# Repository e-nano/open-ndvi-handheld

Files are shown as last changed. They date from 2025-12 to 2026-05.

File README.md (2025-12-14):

# Open NDVI Handheld

**A reference open-source handheld NDVI instrument**

Open-source handheld NDVI device based on the ESP32 Feather V2 and AS7265x Triad spectral sensors, intended as a transparent reference design for vegetation sensing, experimentation, and system integration.

## What is this project?

This repository contains a fully open hardware and software implementation of a handheld NDVI (Normalized Difference Vegetation Index) measurement device.

It is designed to:

- Expose how NDVI measurements are actually produced
- Enable validation, comparison, and experimentation
- Serve as a building block for larger sensing systems

The device measures reflected light in visible and near-infrared bands and computes NDVI locally, producing structured digital output suitable for further analysis or integration.

## Why E-Nano is releasing this

E-Nano develops sensing systems and automation platforms that turn physical measurements into structured, actionable data across multiple industries (sports surfaces, agriculture, construction, and environmental monitoring).

In practice, we repeatedly encountered the same problem:

**Many vegetation indices are treated as "black boxes", making validation, comparison, and integration difficult.**

This project exists to address that problem by providing:

- A transparent reference implementation
- A known, inspectable signal path
- A device that can be understood, modified, and extended

This open handheld NDVI tool is not a commercial product, but a reference instrument that complements E-Nano's wider ecosystem.

## What NDVI means (briefly)

NDVI compares how vegetation reflects:

- **Red light** (absorbed for photosynthesis)
- **Near-infrared light** (strongly reflected by healthy plant structure)

The resulting value typically ranges from:

- **High NDVI (≈ 0.5–0.9)** → healthy, dense vegetation
- **Moderate NDVI (≈ 0.2–0.5)** → stressed or sparse vegetation
- **Low / negative NDVI** → soil, hard surfaces, water

NDVI is an indicator, not a diagnosis, and its reliability depends heavily on measurement context and methodology.

## What this device is intended for

This project is intended for:

- Engineers building or validating sensing systems
- Researchers and students studying vegetation indices
- Turf, agronomy, or environmental professionals exploring NDVI behaviour
- Developers integrating NDVI into larger data pipelines
- Anyone who wants to understand NDVI beyond a single numeric output

It is not intended to replace certified instruments or professional judgement.

## What you will find in this repository

This repository contains everything required to understand and reproduce the device:

### Firmware
- Arduino-based ESP32 code
- NDVI calculation logic
- Sensor configuration and data output

### Hardware
- Full schematic and PCB design (Fusion / Eagle)
- Manufacturing files (Gerbers, BOM)
- Modular carrier-board architecture

### Mechanical
- 3D-printable enclosure (STL + STEP)
- Assembly notes

### Documentation
- Assembly and wiring guides
- NDVI theory and limitations
- Example output data

Nothing is hidden behind proprietary firmware or closed hardware.

## Quick Start Guide

### 📦 **Components Required (~$244 total)**

| Component | Cost | Supplier |
|---|---|---|
| [ESP32 Feather V2](https://www.adafruit.com/product/5400) | $22.50 | Adafruit |
| [2x AS7265x Sensors](https://www.sparkfun.com/products/15050) | $74.95 each | SparkFun |
| [240x240 LCD Display](https://shop.pimoroni.com/products/1-3-spi-colour-lcd-240x240-breakout) | $16.50 | Pimoroni |
| [LiPo Battery](https://shop.pimoroni.com/products/lipo-battery-pack) | $12.00 | Pimoroni |
| Custom Carrier PCB | ~$20 | PCB Manufacturer |
| 3D Printed Enclosure | ~$15 | 3D Printing Service |
| Switches & Connectors | ~$8 | Generic |

### 🔧 **Build Process**

1. **Order components** and send `hardware/gerbers/` files to PCB manufacturer
2. **Assemble** carrier PCB with all modules (see [Assembly Guide](docs/assembly_guide.md))
3. **Program firmware** using Arduino IDE (see setup below)
4. **Test device** and take first measurements

### 💻 **Arduino IDE Setup**

1. **Install Arduino IDE** from [arduino.cc](https://www.arduino.cc/)

2. **Add ESP32 Board Support:**
   - File → Preferences
   - Additional Board Manager URLs: `https://espressif.github.io/arduino-esp32/package_esp32_dev_index.json`
   - Tools → Board → Boards Manager → Search "esp32" → Install

3. **Install Libraries** (Library Manager):
   - SparkFun AS7265x Arduino Library
   - Adafruit ST7735 and ST7789 Library
   - Adafruit GFX Library

4. **Programming:**
   - Connect ESP32 via USB
   - Board: "Adafruit ESP32 Feather"
   - Open: `firmware/ndvi_handheld/ndvi_handheld.ino`
   - Upload ⬆️

### 📱 **Using the Device**

**Display shows:**
- **Large NDVI number** (color-coded: green=healthy, yellow=moderate, white=sparse)
- **Battery percentage**
- **"LOW LIGHT"** warning when too dark for accurate readings

## Design philosophy

Key principles behind this project:

**Transparency over optimisation**
Readability and traceability are prioritised over maximum performance.

**Reference, not product**
This is a baseline instrument meant to be built upon.

**Interoperability**
Data output is designed to be easy to log, parse, and integrate.

**Modularity**
Firmware, hardware, and enclosure can all be adapted independently.

## Relationship to E-Nano's commercial systems

This open project:

- Does not include E-Nano's proprietary analysis pipelines
- Does not include commercial calibration workflows
- Does not claim agronomic decision-making accuracy

E-Nano's commercial offerings build on similar sensing principles, but add:

- Controlled calibration
- Repeatability guarantees
- Quality assurance
- Integration into larger automation and analysis platforms

This repository exists to enable understanding and experimentation, not to replace professional systems.

## Repository structure (high level)

```
open-ndvi-handheld/
├── firmware/        # ESP32 firmware (Arduino)
├── hardware/        # Schematic, PCB, BOM, Gerbers
├── mechanical/      # 3D-printable enclosure
├── docs/            # Assembly, theory, documentation
└── LICENSES/        # Multi-license structure
```

## Licensing

Different parts of the project use appropriate open licences:

- **Firmware**: MIT
- **Hardware (schematic & PCB)**: CERN OHL-W v2
- **Mechanical design**: CC BY-SA 4.0
- **Documentation**: CC BY 4.0

See the `LICENSES/` directory for full texts.

## Documentation

- 🔧 [Assembly Guide](docs/assembly_guide.md) - Detailed assembly instructions
- 📐 [Wiring & Pinout](docs/wiring_and_pinout.md) - Technical connections
- 🧪 [NDVI Theory](docs/ndvi_theory.md) - Scientific background
- ❓ [FAQ](docs/faq.md) - Common questions and troubleshooting

## Contributing

Contributions are welcome, particularly:

- Documentation improvements
- Validation experiments
- Firmware extensions
- Mechanical or hardware variants

Please read:

- [CONTRIBUTING.md](CONTRIBUTING.md)
- [CODE_OF_CONDUCT.md](CODE_OF_CONDUCT.md)

## Disclaimer

This is an experimental reference instrument provided as-is.

It is not certified, not safety-critical, and not intended to be used as the sole basis for agronomic or environmental decisions.

Released by E-Nano to support transparency, learning, and open experimentation in vegetation sensing.

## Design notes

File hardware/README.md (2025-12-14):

# Hardware - Open NDVI Handheld

This directory contains all hardware design files for the Open NDVI Handheld device.

## Overview

The hardware consists of a custom carrier PCB designed to connect modular components: ESP32 Feather V2, dual AS7265x spectral sensors, ST7789 240x240 LCD display, battery, switches, and connectors. This modular approach simplifies assembly, troubleshooting, and component replacement.

## Directory Structure

- `fusion_eagle/` - Autodesk Fusion/Eagle design files
- `gerbers/` - Manufacturing files for PCB production
- `bom/` - Bill of Materials
- `outputs/` - Generated documentation (schematics, assembly drawings)
- `datasheets/` - Component datasheets (AS7265x, ESP32, SSD1351, etc.)

## Design Files

### Fusion/Eagle Files
- `ndvi_v1.sch` - Schematic design
- `ndvi_v1.brd` - PCB layout
- `ndvi_v1.f3d` - Fusion 360 3D model
- `ndvi_v1.f2d` - Fusion 360 2D drawings

### Manufacturing Outputs
- `gerbers/ndvi_gerbers.zip` - Gerber files for PCB fabrication
- `bom/bom.csv` - Complete bill of materials
- `outputs/schematic.pdf` - Printable schematic
- `outputs/pcb_top.pdf` - Top layer assembly drawing
- `outputs/pcb_bottom.pdf` - Bottom layer assembly drawing

## Key Components

- **ESP32 Feather V2** (Adafruit #5400) - Main microcontroller with WiFi/Bluetooth
- **2x AS7265x Triad Sensors** (SparkFun SEN-15050) - 18-channel spectral sensors
- **ST7789 240x240 LCD** (Pimoroni 1.3" SPI) - Color display with simplified interface
- **LiPo Battery** (Pimoroni) - Rechargeable power source
- **Power Switch** - On/off control
- **Momentary Button** - Measurement trigger (A0)
- **Carrier PCB** - Custom board connecting all modules
- **Headers/Connectors** - Modular connections for easy assembly

## PCB Specifications

- 4-layer PCB design
- Dimensions: TBD
- Thickness: 1.6mm standard
- Finish: HASL or ENIG
- Via size: 0.2mm minimum

## Assembly Notes

See `mechanical/assembly_notes.md` for complete assembly instructions.

## License

Hardware designs are licensed under CERN OHL-W v2. See `LICENSES/LICENSE_HARDWARE_CERN-OHL-W.txt`.

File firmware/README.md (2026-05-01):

# Firmware - Open NDVI Handheld

- This folder now contains the ESP32 firmware structure copied from `Manti-S_CalibrationCode`.

## Layout

- `platformio.ini`
  - PlatformIO project config for `adafruit_feather_esp32_v2`
- `src/main.cpp`
  - Main ESP32 application
- `src/as7265x_calibration_data.h`
  - Embedded calibration tables
- `lib/SparkFun_Spectral_Triad_AS7265X/`
  - Local patched AS7265X library used by the firmware
- `ndvi_handheld/ndvi_handheld.ino`
  - Older Arduino sketch retained for reference

## Notes

- The active PlatformIO firmware is the `src/` project, not the older `.ino` sketch.
- The copied firmware includes:
  - Dual AS7265X sensor handling
  - ST7789 display output
  - Battery monitoring
  - BLE status service
  - Calibration storage via `Preferences`

## Build

```bash
cd /home/robert/Documents/Manti-S/open-ndvi-handheld/firmware
pio run
```

## Upload

```bash
cd /home/robert/Documents/Manti-S/open-ndvi-handheld/firmware
pio run --target upload
```

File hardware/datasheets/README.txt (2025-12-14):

# Component Datasheets

This directory contains datasheets for the hardware components used in the Open NDVI Handheld device.

## Files to add:
- AS7265x_datasheet.pdf (SparkFun AS7265x Triad Spectral Sensor)
- ESP32_datasheet.pdf (ESP32 microcontroller specifications)
- SSD1351_datasheet.pdf (OLED display controller)
- Other component datasheets as needed

Drop your AS7265x datasheet PDF file here.

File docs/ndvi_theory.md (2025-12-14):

# NDVI Explanation and Measurement Principles

## Purpose of this document

This document explains what NDVI is, how it is measured, and how it is implemented in this device.

The goal is not to present NDVI as a black-box metric, but to clarify:

- What physical quantities are being measured
- How those measurements are combined
- What assumptions are involved
- Where limitations arise

This aligns with the project's intent as a reference and learning instrument, not a certified diagnostic tool.

## What NDVI is

NDVI (Normalized Difference Vegetation Index) is a numerical indicator that relates plant health to how vegetation interacts with light.

It is based on two well-established observations:

- **Healthy vegetation absorbs red light** for photosynthesis
- **Healthy vegetation reflects near-infrared (NIR) light** due to internal leaf structure

NDVI combines these two effects into a single normalized value:

```
NDVI = (NIR − RED) / (NIR + RED)
```

The resulting value typically ranges between –1 and +1.

## Interpreting NDVI values

While exact thresholds depend on context, typical interpretations are:

**0.5 – 0.9**
Dense, healthy vegetation

**0.2 – 0.5**
Sparse, stressed, or partially senescent vegetation

**0.0 – 0.2**
Very sparse vegetation or mixed soil/background

**< 0.0**
Non-vegetated surfaces such as soil, concrete, or water

NDVI indicates relative vegetation condition, not a specific diagnosis.

## What is actually measured

**NDVI is not measured directly.**
It is computed from measurements of reflected light.

This device measures:

- Spectral intensity in discrete wavelength bands
- Using calibrated photodiode-based spectral sensors
- Across both visible and near-infrared regions

Each measurement represents relative reflected light intensity, not absolute radiance.

## Why this device uses two spectral sensors

### The challenge of outdoor measurements

In real outdoor conditions, illumination is constantly changing due to:

- Sun angle
- Cloud cover
- Shadows
- Atmospheric conditions

If illumination changes, reflected light measurements change — even if vegetation does not.

### Downward-facing sensor (surface reflectance)

The downward-facing sensor measures light reflected from the surface beneath the device.

This sensor captures:

- Reflected red light
- Reflected near-infrared light
- A mixture of vegetation and background within its field of view

This measurement contains the vegetation signal of interest.

### Upward-facing sensor (incident illumination)

The upward-facing sensor measures the ambient light illuminating the scene.

This sensor captures:

- The spectral composition of incoming light
- Short-term changes caused by clouds or sun angle
- Overall illumination intensity

This represents what light is available at the time of measurement.

### Why both are used together

Using only a downward-facing sensor assumes stable illumination, which is rarely true outdoors.

By measuring both:

- **Incident light** (upward-facing sensor)
- **Reflected light** (downward-facing sensor)

the system can normalise reflected measurements against current lighting conditions.

This improves:

- Measurement repeatability
- Comparability between consecutive readings
- Interpretation under changing weather conditions

This approach mirrors techniques used in professional field spectrometers and handheld vegetation sensors.

## How NDVI is computed in this device

At a high level, the process is:

1. Measure incident spectral light (upward sensor)
2. Measure reflected spectral light (downward sensor)
3. Select appropriate bands to represent RED and NIR
4. Apply normalisation and averaging
5. Compute NDVI using the standard formula

The exact band selection and processing steps are documented in the firmware.

This is a band-based approximation of NDVI, not a hyperspectral implementation.

## Assumptions and limitations

It is important to understand what this design assumes:

- Illumination is reasonably uniform within the sensor field of view
- The measured area is dominated by the surface of interest
- Sensor temperature and electronics remain stable over short intervals
- Measurements are relative, not absolutely calibrated radiance

Known limitations include:

- Mixed pixels (vegetation + soil)
- Strong shadows or specular reflections
- Very sparse or very dense canopies
- Artificial or highly directional lighting

The upward-facing sensor improves consistency, but does not eliminate all sources of error.

## What this device does not claim

This device does not claim:

- Absolute radiometric calibration
- Satellite-level NDVI equivalence
- Disease detection or agronomic prescription
- Certified measurement accuracy

It is intended as a transparent reference implementation, not a decision-making authority.

## Why this explanation matters

NDVI values are often treated as single numbers without context.

This project intentionally exposes:

- The physics behind the measurement
- The assumptions involved
- The reasons values may vary

Understanding these factors leads to better interpretation, better validation, and more responsible use of NDVI data.

## Summary

This device implements NDVI using discrete spectral measurements of red and near-infrared light, combined with incident-light normalisation via a dual-sensor design. The approach improves repeatability in real-world conditions while remaining transparent about assumptions and limitations. The goal is understanding and experimentation, not black-box output.

---

*License: CC BY 4.0*

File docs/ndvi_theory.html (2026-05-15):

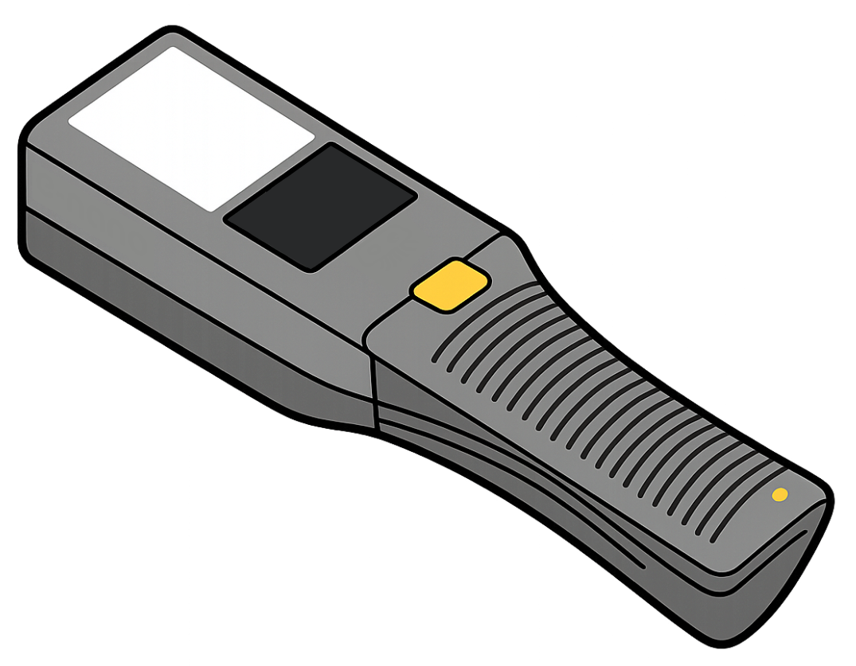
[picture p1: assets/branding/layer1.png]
 MANTI.S by e-nano View Repository (https://github.com/e-nano/open-ndvi-handheld)

Measurement Principles

# NDVI Theory

NDVI is not measured directly. It is computed from red and near-infrared reflectance behaviour, with this device using a dual-sensor design to improve interpretation under changing outdoor light.

RED and NIR band logic Incident light normalisation Reference instrument framing

Definition

## What NDVI is

NDVI relates plant condition to how vegetation interacts with light. Healthy vegetation tends to absorb red light for photosynthesis while reflecting more near-infrared light from internal leaf structure.

NDVI = (NIR - RED) / (NIR + RED)

Interpretation

## Typical value ranges

- 0.5 to 0.9: dense, healthy vegetation
- 0.2 to 0.5: sparse, stressed, or partially senescent vegetation
- 0.0 to 0.2: very sparse vegetation or mixed soil/background
- Below 0.0: soil, concrete, water, or other non-vegetated surfaces

Measurement model

## What this device actually measures

The device measures spectral intensity in discrete wavelength bands using photodiode-based spectral sensors. NDVI is then derived from selected bands representing red and near-infrared response.

- Measurements are relative reflected light intensities.
- The system is not claiming absolute radiometric calibration.
- The firmware documents the exact band selection used for NDVI calculation.

Why two sensors

## Incident and reflected light

Outdoor illumination is unstable. Cloud cover, solar angle, shadows, and atmosphere all change the available light. A single downward-looking sensor would mix vegetation response with changing illumination.

- UP sensor: measures incident light illuminating the scene
- DOWN sensor: measures reflected light from the target surface

Benefit

## Why the ratio matters

Measuring both incident and reflected light improves repeatability and short-term comparability by normalising the vegetation signal against the illumination conditions at the moment of capture.

Limits

## Assumptions and constraints

- Illumination should be reasonably uniform across the field of view.
- The measured area should mostly contain the intended surface.
- Strong shadows, specular reflections, and mixed backgrounds reduce reliability.
- The device is a transparent reference build, not a certified agronomic instrument.

The purpose of this project is to expose the measurement chain, not to hide it behind a single unexplained number.

Back to home Open assembly guide Read FAQ

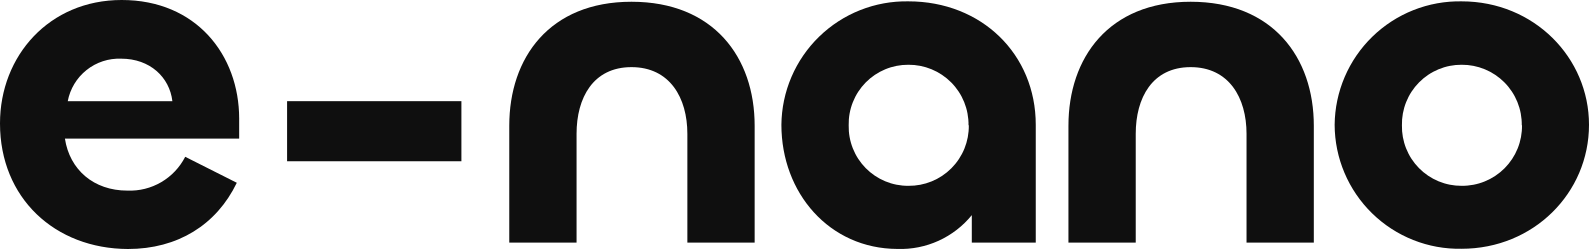
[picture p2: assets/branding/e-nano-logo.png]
e-nano
 Open NDVI Handheld Open reference instrument for vegetation sensing.

Open hardware, firmware, and documentation for field validation and system integration.

Overview Repository Docs Licensing GitHub (https://github.com/e-nano/open-ndvi-handheld)

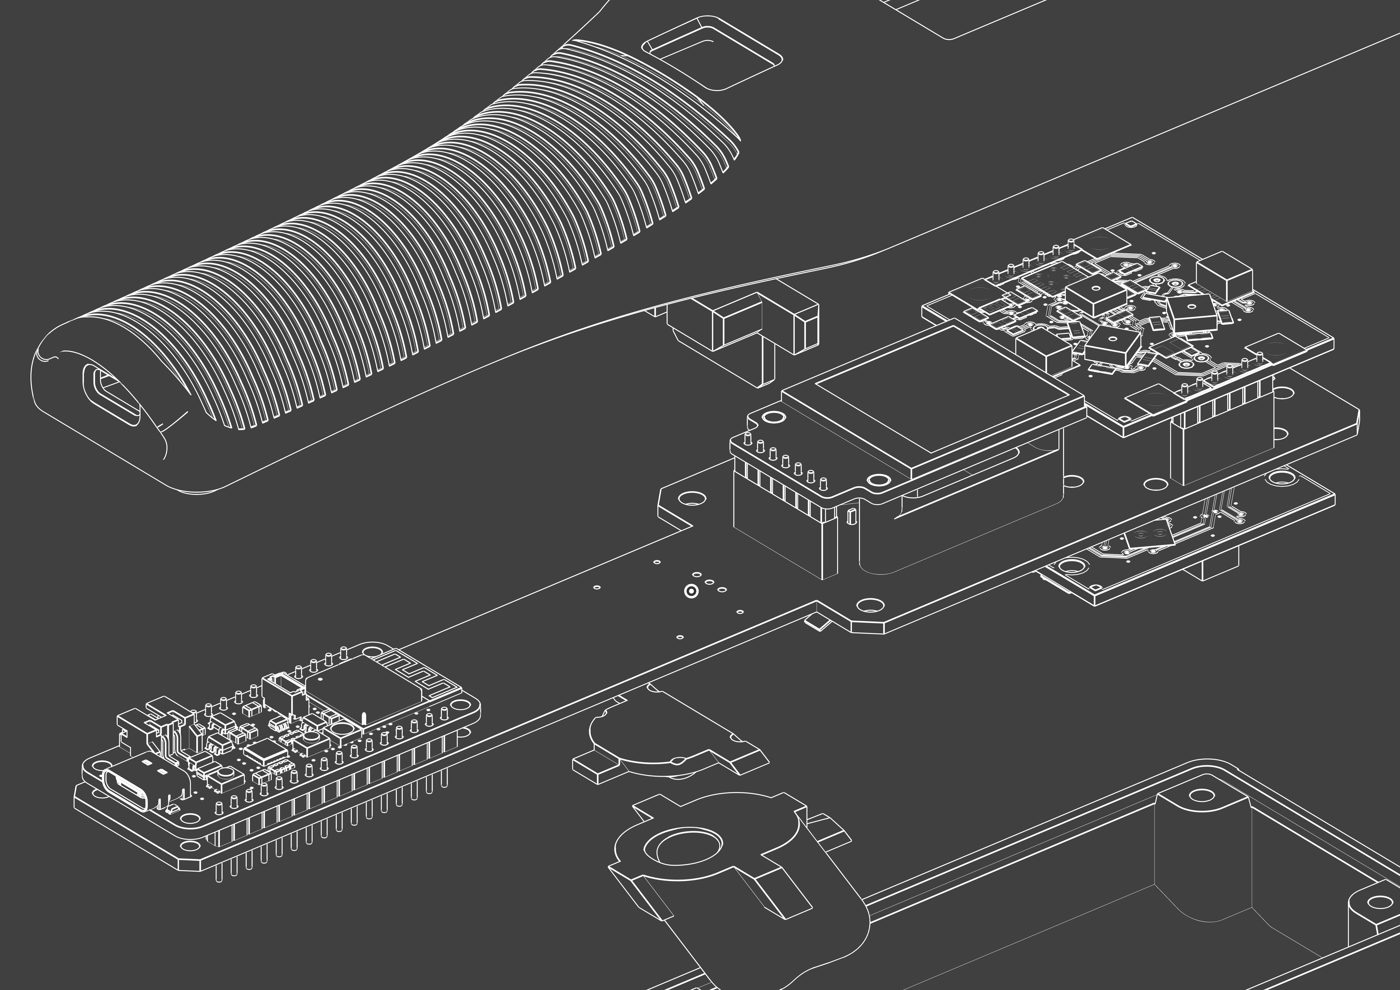
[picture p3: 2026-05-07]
assets/docs/mechanical-expl-view.png

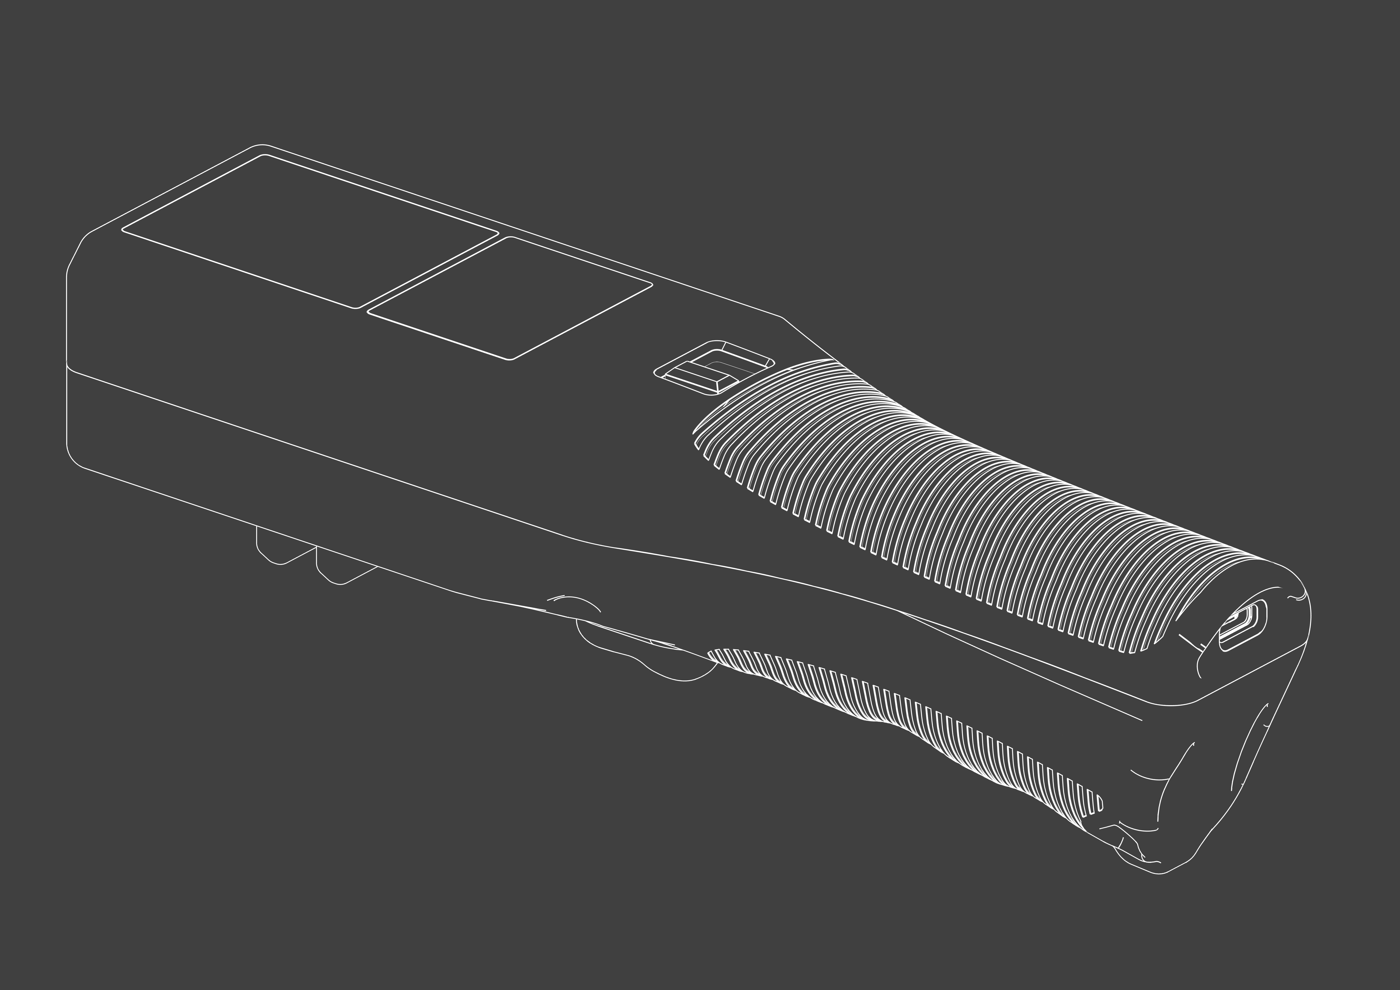
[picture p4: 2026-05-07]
assets/docs/device-side-view.png

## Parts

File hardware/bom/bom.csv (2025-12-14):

Reference | Quantity | Value | Description | Manufacturer | Part Number | Supplier | Supplier Link | Estimated Cost
MCU1 | 1 | ESP32-S3 Feather V2 | ESP32-S3 Feather with WiFi/Bluetooth | Adafruit | 5400 | Adafruit | https://www.adafruit.com/product/5400 | $22.50
SENSOR1 | 1 | AS7265x Triad | Spectral Sensor UP (incident light) | SparkFun | SEN-15050 | SparkFun | https://www.sparkfun.com/products/15050 | $74.95
SENSOR2 | 1 | AS7265x Triad | Spectral Sensor DOWN (reflected light) | SparkFun | SEN-15050 | SparkFun | https://www.sparkfun.com/products/15050 | $74.95
DISP1 | 1 | 1.3" SPI LCD | 240x240 Color LCD with ST7789 controller | Pimoroni | - | Pimoroni | https://shop.pimoroni.com/products/1-3-spi-colour-lcd-240x240-breakout | $16.50
BAT1 | 1 | LiPo Battery | 3.7V Lithium Polymer battery pack | Pimoroni | - | Pimoroni | https://shop.pimoroni.com/products/lipo-battery-pack | $12.00
PCB1 | 1 | Custom PCB | Carrier board for component integration | Custom Design | - | PCB Manufacturer | - | $20.00
SW1 | 1 | Power Switch | On/Off power switch | Generic | - | Generic Supplier | - | $2.00
SW2 | 1 | Tactile Switch | Momentary push button for measurements | Generic | - | Generic Supplier | - | $1.00
CONN1 | Various | Headers/Connectors | Connection hardware for modules | Generic | - | Generic Supplier | - | $5.00
ENCL1 | 1 | 3D Printed Enclosure | Housing for complete assembly | Custom Design | - | 3D Printing Service | - | $15.00
#
# Assembly Notes:
# - Custom carrier PCB connects all modules via headers/connectors
# - ESP32 Feather V2 provides main processing and connectivity
# - Dual AS7265x sensors measure incident and reflected light
# - ST7789 240x240 display shows NDVI values and battery status
# - Simple interface: large NDVI number or "LOW LIGHT" warning
#
# Total estimated cost: ~$244 (excluding shipping)

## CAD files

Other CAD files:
hardware/fusion_eagle/ndvi_v1.f2d
hardware/fusion_eagle/ndvi_v1.f3d

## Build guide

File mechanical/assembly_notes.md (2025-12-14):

# Assembly Notes - Open NDVI Handheld

## Overview
The Open NDVI Handheld uses a modular assembly approach with a custom carrier PCB that connects all major components via headers and connectors.

## Components Required
- ESP32 Feather V2 (Adafruit #5400)
- 2x SparkFun AS7265x Triad Sensors (SEN-15050)  
- Pimoroni 1.3" SPI LCD 240x240 (ST7789)
- Pimoroni LiPo Battery Pack
- Custom Carrier PCB
- Power switch
- Momentary push button
- Headers and connectors
- 3D printed enclosure

## Assembly Steps
1. Install headers on carrier PCB
2. Mount ESP32 Feather V2 to carrier board
3. Connect both AS7265x sensors via I2C:
   - UP sensor: incident light measurement
   - DOWN sensor: reflected light measurement  
4. Connect ST7789 display via SPI
5. Wire power switch and measurement button
6. Connect LiPo battery
7. Test all connections
8. Install in 3D printed enclosure

## Connections Summary
- ESP32 Feather V2: Main processing unit
- AS7265x UP sensor: I2C2 (SDA, SCL pins)
- AS7265x DOWN sensor: I2C1 (D7, A4 pins)
- ST7789 Display: SPI (CS=D6, DC=D2, RST=D3)
- Button: Pin A0 (with pullup)
- Battery Monitor: Pin A3

## Notes
- Modular design allows easy component replacement
- All major components are socketed/removable
- Carrier PCB simplifies wiring and assembly
- 3D printed enclosure protects components

## License
Assembly documentation licensed under CC BY-SA 4.0

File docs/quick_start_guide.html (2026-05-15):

 MANTI.S by e-nano View Repository (https://github.com/e-nano/open-ndvi-handheld)

User Guide

# Manti.S Quickstart Guide

Thank you for purchasing the MANTI-S portable NDVI sensor. Each Manti-S device is individually calibrated to produce standardised NDVI values.

Portable NDVI sensor Standardised calibrated output Field-use handling guide

Taking measurements

## Using the device

1. Hold the Manti.S over the area to be measured.
2. Press the trigger until a value for NDVI is displayed.
3. For best results, hold the device parallel to the ground when taking measurements.
4. Use the device during daylight hours.
5. Ensure that the white diffuser on the top of the device is clean of dirt and debris.

Taking measurements

## Measurement Conditions

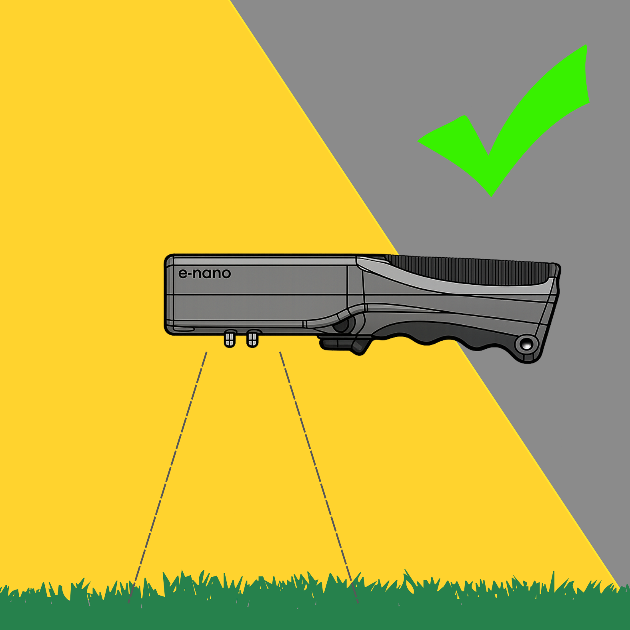
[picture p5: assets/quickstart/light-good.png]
Correct MANTI-S positioning over grass with a green check mark.


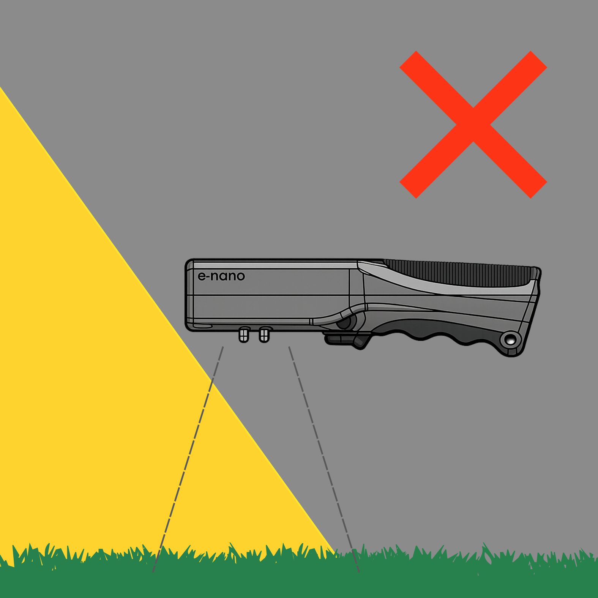
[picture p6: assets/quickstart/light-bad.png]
Incorrect MANTI-S positioning with the device tilted and a red X.


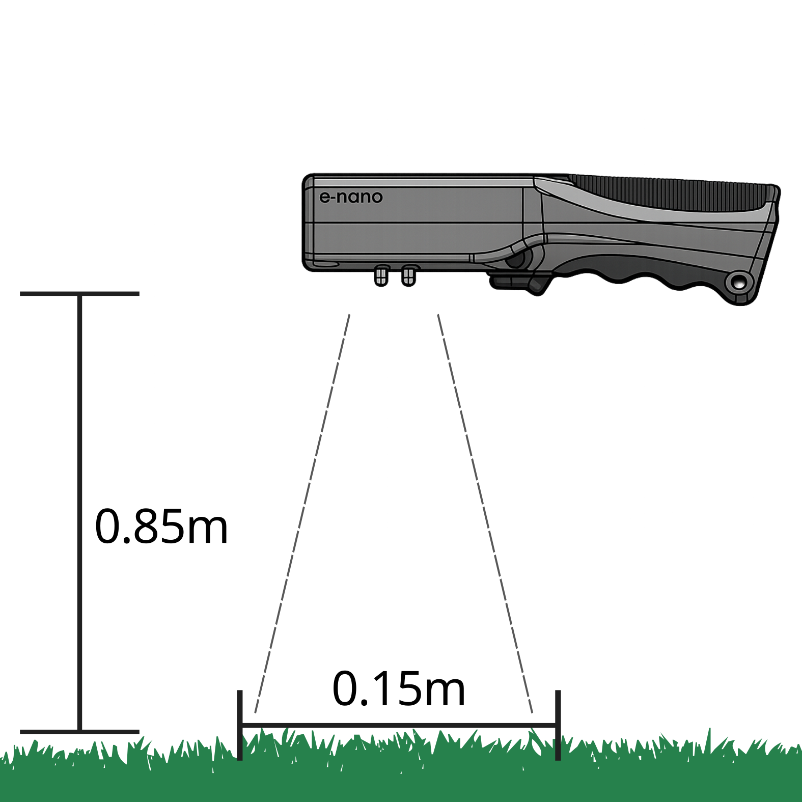
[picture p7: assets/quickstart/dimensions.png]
MANTI-S shown above grass with a suggested measurement height of 0.85m and footprint width of 0.15m.


Things that affect your values

## Differing sensor light conditions

The Manti.S uses a matched pair of sensors to calculate NDVI. This means the white diffuser on the top of the device must be in the same light conditions as the area being measured, otherwise values will be skewed.

## Wet ground

Ratios of IR and red light from wet soil can inflate measurements.

## Low light

When the device indicates "low light" it is sensing weak signals from the bottom sensor and measurements may be partially less accurate.

e-nano Open NDVI Handheld Open reference instrument for vegetation sensing.

Open hardware, firmware, and documentation for field validation and system integration.

Overview Repository Docs Licensing GitHub (https://github.com/e-nano/open-ndvi-handheld)

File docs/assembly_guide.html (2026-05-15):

 MANTI.S by e-nano View Repository (https://github.com/e-nano/open-ndvi-handheld)

Build Guide

# Assembly Guide

A concise build flow for the carrier PCB, dual AS7265x sensors, display, controls, battery, and enclosure.

Carrier PCB architecture Dual-sensor handheld build Reference documentation

Overview

## What this build includes

The Open NDVI Handheld uses a modular assembly approach. A custom carrier PCB hosts the ESP32 Feather V2, two AS7265x Triad sensors, an ST7789 LCD, the measurement button, power switch, and the battery connection.

View wiring and pinout Read troubleshooting FAQ

Parts

## Required components

- Adafruit ESP32 Feather V2
- 2x SparkFun AS7265x Triad spectral sensors
- Pimoroni 1.3" 240x240 SPI LCD with ST7789 controller
- Single-cell LiPo battery
- Custom carrier PCB
- Power switch and momentary measurement button
- Headers, connectors, and 3D printed enclosure parts

Preparation

## Before assembly

- Fabricate the carrier PCB from the Gerbers in `hardware/gerbers/`.
- Review `hardware/outputs/pcb_top.pdf` and `pcb_bottom.pdf`.
- Print the enclosure parts from `mechanical/` if you want a full housing.
- Confirm the firmware target is the ESP32 Feather V2 project in `firmware/src/`.

Sequence

## Recommended assembly order

1. Install headers and board-to-board connectors on the carrier PCB.
2. Mount the ESP32 Feather V2 to the carrier board.
3. Mount and connect the upward-facing AS7265x sensor for incident light measurement.
4. Mount and connect the downward-facing AS7265x sensor for reflected light measurement.
5. Connect the ST7789 display over SPI.
6. Wire the power switch and the measurement button.
7. Connect the LiPo battery and verify battery monitor routing.
8. Test power, display, both I2C buses, and the button before closing the enclosure.
9. Install the assembled electronics into the printed enclosure.

Checks

## Bring-up checklist

- ESP32 powers and enumerates over USB.
- Display backlight turns on.
- Both sensors initialise without bus collisions.
- Battery percentage appears on-screen.
- Measurement button triggers a reading.

Notes

## Assembly intent

- The project is modular by design, so component replacement is straightforward.
- The dual-sensor layout is central to the incident/reflected light workflow.
- Use the wiring page for the actual pin mapping before soldering permanent connections.

Next

## After physical assembly

Once the hardware is assembled, program the Feather with the PlatformIO project in `firmware/`, then verify the display, sensor readings, battery sampling, and BLE status behaviour.

Back to home Open wiring guide Read NDVI theory

e-nano Open NDVI Handheld Open reference instrument for vegetation sensing.

Open hardware, firmware, and documentation for field validation and system integration.

Overview Repository Docs Licensing GitHub (https://github.com/e-nano/open-ndvi-handheld)

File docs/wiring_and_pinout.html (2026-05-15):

 MANTI.S by e-nano View Repository (https://github.com/e-nano/open-ndvi-handheld)

Electrical Reference

# Wiring and Pinout

The current firmware uses two I2C buses, one SPI display connection, a dedicated measure button, display backlight control, and battery sensing.

Dual I2C buses SPI display interface ESP32 Feather V2 target

Firmware mapping

## Pin summary from the active ESP32 firmware

Function | Firmware symbol | Pin | Use
DOWN sensor SDA | `I2C1_SDA_PIN` | `33` | Custom I2C bus for reflected-light sensor
DOWN sensor SCL | `I2C1_SCL_PIN` | `13` | Custom I2C bus clock for reflected-light sensor
UP sensor SDA | `I2C2_SDA_PIN` | `SDA` | Default I2C bus for incident-light sensor
UP sensor SCL | `I2C2_SCL_PIN` | `SCL` | Default I2C bus clock for incident-light sensor
Display chip select | `TFT_CS` | `A0` | ST7789 SPI chip select
Display data/command | `TFT_DC` | `A1` | ST7789 command/data select
Display reset | `TFT_RST` | `-1` | No dedicated reset line in the active firmware
Display backlight | `TFT_BL` | `A5` | Backlight enable control
Measure button | `BTN_MEASURE` | `A2` | Manual reading trigger
Battery monitor | `BATT` | `A3` | ADC battery sense input

Sensors

## Why two I2C buses are used

The firmware treats the upward-facing and downward-facing AS7265x modules as separate buses. That avoids address conflicts and supports the dual-sensor incident-versus-reflected measurement approach.

- UP sensor: ambient or incident illumination
- DOWN sensor: reflected signal from the target surface

Display

## Display integration

The interface is built around a 240x240 ST7789 screen. The active firmware controls the backlight separately and expects a no-reset configuration.

TFT_CS  = A0
TFT_DC  = A1
TFT_RST = -1
TFT_BL  = A5

System notes

## Additional interface details

- The active BLE advertising name in firmware is `Manti-S-00001`.
- The measure button and battery ADC live on analog-capable Feather pins.
- The wiring should follow the carrier PCB rather than freehand prototyping assumptions.
- Always cross-check this page against the board files in `hardware/fusion_eagle/`.

The pin mapping on this page reflects the current `firmware/src/main.cpp` that was copied into the repository. If firmware pin definitions change, this page should change with them.

Back to home Open assembly guide Open FAQ

e-nano Open NDVI Handheld Open reference instrument for vegetation sensing.

Open hardware, firmware, and documentation for field validation and system integration.

Overview Repository Docs Licensing GitHub (https://github.com/e-nano/open-ndvi-handheld)

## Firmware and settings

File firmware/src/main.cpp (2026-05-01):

/***************************************************
  AS7265X dual-sensor outdoor NDVI meter (ESP32)

  - Bulbs OFF (ambient light)
  - Uses channels I (red-ish) and V (NIR-ish) for NDVI
  - UP sensor: incident light (sky) on Wire1 (default SDA/SCL)
  - DOWN sensor: reflected light (turf) on Wire (custom GPIOs on PCB)
  - Shows NDVI + battery % on ST7789 240x240 LCD (Pimoroni 1.3")
  - Measures when BTN_MEASURE is pressed OR serial 'm' received
  - Single measurement per press: UP then DOWN, ratio-based NDVI
  - No grey-panel calibration — reflectance ratios used directly

  Serial commands (115200 baud):
    m  or  M  — trigger a measurement (newline also accepted)

  IMPORTANT (Pimoroni 1.3" ST7789 240x240 SPI):
  - No RST pin -> TFT_RST = -1
  - BL is backlight enable, drive separately

  Hot-plug behaviour:
  - Sketch will boot if sensors are missing
  - It keeps retrying init in the background

  REQUIRES: SparkFun AS7265X library patched to accept a TwoWire&
  argument in begin(). The stock library always uses Wire; without
  this patch both sensors share the same bus and collide.
****************************************************/

#include "SparkFun_AS7265X.h"
#include "as7265x_calibration_data.h"
#include <Wire.h>
#include <WiFi.h>
#include <Preferences.h>
#include <BLEDevice.h>
#include <BLEUtils.h>
#include <BLEServer.h>
#include <Adafruit_GFX.h>
#include <Adafruit_ST7789.h>
#include <SPI.h>
#include <freertos/FreeRTOS.h>
#include <freertos/semphr.h>

// ---------------- I2C ----------------
// DOWN sensor on custom pins (cannot change due to PCB)
#define I2C1_SDA_PIN 33
#define I2C1_SCL_PIN 13

// UP sensor on default SDA/SCL (Wire1)
#define I2C2_SDA_PIN SDA
#define I2C2_SCL_PIN SCL

AS7265X sensor_DOWN;
AS7265X sensor_UP;

Preferences calibration_preferences;

bool up_ok   = false;
bool down_ok = false;

// Retry logic
unsigned long last_sensor_retry_ms = 0;
const unsigned long SENSOR_RETRY_PERIOD_MS = 1000;

// ---------------- ST7789 240x240 LCD ----------------
#define SCREEN_WIDTH  240
#define SCREEN_HEIGHT 240

#define TFT_CS  A0
#define TFT_DC  A1
#define TFT_RST -1
#define TFT_BL  A5

Adafruit_ST7789 tft = Adafruit_ST7789(TFT_CS, TFT_DC, TFT_RST);

// Colors (565)
#define BLACK  0x0000
#define GREEN  0x07E0
#define RED    0xF800
#define YELLOW 0xFFE0
#define CYAN   0x07FF
#define GREY   0x8410
#define WHITE  0xFFFF

// ---------------- Button ----------------
#define BTN_MEASURE A2
bool lastMeasureState = false;

static constexpr const char *CALIBRATION_FW_ID = "Manti-S-Cal";
static constexpr const char *CALIBRATION_NAMESPACE = "mantiscal";
static constexpr const char *CALIBRATION_KEY = "blob";
static constexpr uint32_t CALIBRATION_MAGIC = 0x4D534341UL;
static constexpr uint16_t CALIBRATION_VERSION = 2;
static constexpr size_t SERIAL_COMMAND_MAX_TOKENS =
  (4 + (2 * AS7265X_CAL_POINT_COUNT) > 2 + AS7265X_CHANNEL_COUNT)
    ? 4 + (2 * AS7265X_CAL_POINT_COUNT)
    : 2 + AS7265X_CHANNEL_COUNT;
static constexpr size_t RED_CHANNEL_INDEX = 9;
static constexpr size_t NIR_CHANNEL_INDEX = 14;

static const char *CHANNEL_LABELS[AS7265X_CHANNEL_COUNT] = {
  "A", "B", "C", "D", "E", "F", "G", "H", "R",
  "I", "S", "J", "T", "U", "V", "W", "K", "L"
};

static const uint16_t CHANNEL_WAVELENGTHS[AS7265X_CHANNEL_COUNT] = {
  410, 435, 460, 485, 510, 535, 560, 585, 610,
  645, 680, 705, 730, 760, 810, 860, 900, 940
};

static float UP_DARK_OFFSETS[AS7265X_CHANNEL_COUNT] = {0.0f};
static float DOWN_DARK_OFFSETS[AS7265X_CHANNEL_COUNT] = {0.0f};
static bool calibration_loaded_from_flash = false;

struct CalibrationBlob {
  uint32_t magic;
  uint16_t version;
  uint16_t reserved;
  float up_inputs[AS7265X_CHANNEL_COUNT][AS7265X_CAL_POINT_COUNT];
  float up_factors[AS7265X_CHANNEL_COUNT][AS7265X_CAL_POINT_COUNT];
  float down_inputs[AS7265X_CHANNEL_COUNT][AS7265X_CAL_POINT_COUNT];
  float down_factors[AS7265X_CHANNEL_COUNT][AS7265X_CAL_POINT_COUNT];
  float up_dark_offsets[AS7265X_CHANNEL_COUNT];
  float down_dark_offsets[AS7265X_CHANNEL_COUNT];
};

struct SensorCalibrationView {
  const char *name;
  AS7265X *sensor;
  bool *ready_flag;
  float (*inputs)[AS7265X_CAL_POINT_COUNT];
  float (*factors)[AS7265X_CAL_POINT_COUNT];
  float *dark_offsets;
};

// ---------------- Battery ----------------
#define BATT A3

// ADC correction factor measured empirically for this board.
// Multiply the raw ESP32 ADC voltage by this to get true voltage.
// Re-measure with a multimeter if the board changes.
#define ADC_CORRECTION_FACTOR 1.065f

float batt_v_avg = 0.0f;
int battery_soc  = 0;

// Battery is sampled periodically in the main loop.
unsigned long last_batt_sample_ms = 0;
const unsigned long BATT_SAMPLE_PERIOD_MS = 5000;

static const float voltagePoints[] = {
  3.30f, 3.45f, 3.55f, 3.68f, 3.73f, 3.79f,
  3.85f, 3.92f, 4.00f, 4.08f, 4.12f, 4.20f
};

static const float socPoints[] = {
   0,  10,  20,  30,  40,  50,
  60,  70,  80,  90,  95, 100
};

static inline float clampf(float x, float lo, float hi) {
  if (x < lo) return lo;
  if (x > hi) return hi;
  return x;
}

float voltageToPercent(float v) {
  const int N = sizeof(voltagePoints) / sizeof(voltagePoints[0]);
  if (v <= voltagePoints[0])     return 0.0f;
  if (v >= voltagePoints[N - 1]) return 100.0f;
  for (int i = 0; i < N - 1; i++) {
    if (v >= voltagePoints[i] && v <= voltagePoints[i + 1]) {
      float t = (v - voltagePoints[i]) / (voltagePoints[i + 1] - voltagePoints[i]);
      return socPoints[i] + t * (socPoints[i + 1] - socPoints[i]);
    }
  }
  return 0.0f;
}

void configure_batt() {
  pinMode(BATT, INPUT);
  analogSetPinAttenuation(BATT, ADC_11db);
}

int read_voltage_percent() {
  uint16_t raw = analogRead(BATT);
  float voltage = (raw / 4095.0f) * 3.3f * ADC_CORRECTION_FACTOR * 2.0f;

  if (batt_v_avg == 0.0f) {
    batt_v_avg = voltage;
  } else {
    batt_v_avg = 0.8f * batt_v_avg + 0.2f * voltage;
  }

  return (int)clampf(voltageToPercent(batt_v_avg), 0.0f, 100.0f);
}

// ---------------- NDVI ----------------
String message_NDVI = "0.00";
float ndvi = 0.0f;
bool last_measurement_low_light = false;
uint32_t measurement_sequence = 0;
unsigned long last_measurement_ms = 0;

// Raw count threshold below which incident light is too low to trust.
const float MIN_INCIDENT_SIGNAL = 75.0f;  // raw counts (0-65535)
const float UP_RED_FROM_NIR_SLOPE = 6.3534f;
const float UP_RED_FROM_NIR_INTERCEPT = -2571.7f;

// Last raw incident readings — used for low-light heuristic.
float last_red_UP = 0.0f;
float last_nir_UP = 0.0f;

// Last calibrated readings for all four channels — displayed on the NDVI screen.
float last_calc_iU = 0.0f;
float last_calc_vU = 0.0f;
float last_calc_iD = 0.0f;
float last_calc_vD = 0.0f;

// ---------------- BLE ----------------
static const char *BLE_DEVICE_NAME  = "Manti-S-00001";
static const char *BLE_SERVICE_UUID = "9f4a6d90-f740-4d10-a947-8c6c20f4f9d1";
static const char *BLE_STATUS_UUID  = "2d86686f-34f8-4f1b-a4ac-f127f90f7df0";

BLEServer         *ble_server                = nullptr;
BLEService        *ble_service               = nullptr;
BLECharacteristic *ble_status_characteristic = nullptr;

static SemaphoreHandle_t ble_mutex = nullptr;
static bool _ble_connected         = false;
static bool _ble_state_dirty       = false;
static bool _ble_ui_dirty          = false;

bool ble_was_connected = false;

static inline void ble_set_connected(bool v) {
  xSemaphoreTake(ble_mutex, portMAX_DELAY);
  _ble_connected   = v;
  _ble_state_dirty = true;
  _ble_ui_dirty    = true;
  xSemaphoreGive(ble_mutex);
}
static inline bool ble_take_state_dirty() {
  xSemaphoreTake(ble_mutex, portMAX_DELAY);
  bool d = _ble_state_dirty;
  _ble_state_dirty = false;
  xSemaphoreGive(ble_mutex);
  return d;
}
static inline bool ble_take_ui_dirty() {
  xSemaphoreTake(ble_mutex, portMAX_DELAY);
  bool d = _ble_ui_dirty;
  _ble_ui_dirty = false;
  xSemaphoreGive(ble_mutex);
  return d;
}
static inline bool ble_is_connected() {
  xSemaphoreTake(ble_mutex, portMAX_DELAY);
  bool v = _ble_connected;
  xSemaphoreGive(ble_mutex);
  return v;
}

enum ScreenMode {
  SCREEN_MODE_STATUS,
  SCREEN_MODE_NDVI,
  SCREEN_MODE_MEASURING
};

ScreenMode current_screen_mode  = SCREEN_MODE_STATUS;
int current_measuring_sample    = 0;
int current_measuring_total     = 1;

class MantisBLEServerCallbacks : public BLEServerCallbacks {
  void onConnect(BLEServer *server) {
    (void)server;
    ble_set_connected(true);
  }
  void onDisconnect(BLEServer *server) {
    ble_set_connected(false);
    server->startAdvertising();
  }
};

// ---------------- Forward declarations ----------------
void drawHeaderStatus();
void drawStatusScreen();
void drawNDVIScreen();
void drawMeasuringScreen(int currentSample, int totalSamples);
void redrawCurrentScreen();
void setupBLE();
void serviceBLE();
void updateBLEStatusValue();
bool poll_serial_commands();

bool get_sensor_calibration_view(const char *sensor_name, SensorCalibrationView &view) {
  if (strcmp(sensor_name, "up") == 0) {
    view = {"up", &sensor_UP, &up_ok, UP_CAL_INPUTS, UP_CAL_FACTORS, UP_DARK_OFFSETS};
    return true;
  }
  if (strcmp(sensor_name, "down") == 0) {
    view = {"down", &sensor_DOWN, &down_ok, DOWN_CAL_INPUTS, DOWN_CAL_FACTORS, DOWN_DARK_OFFSETS};
    return true;
  }
  return false;
}

void fill_calibration_blob(CalibrationBlob &blob) {
  blob.magic = CALIBRATION_MAGIC;
  blob.version = CALIBRATION_VERSION;
  blob.reserved = 0;
  memcpy(blob.up_inputs, UP_CAL_INPUTS, sizeof(UP_CAL_INPUTS));
  memcpy(blob.up_factors, UP_CAL_FACTORS, sizeof(UP_CAL_FACTORS));
  memcpy(blob.down_inputs, DOWN_CAL_INPUTS, sizeof(DOWN_CAL_INPUTS));
  memcpy(blob.down_factors, DOWN_CAL_FACTORS, sizeof(DOWN_CAL_FACTORS));
  memcpy(blob.up_dark_offsets, UP_DARK_OFFSETS, sizeof(UP_DARK_OFFSETS));
  memcpy(blob.down_dark_offsets, DOWN_DARK_OFFSETS, sizeof(DOWN_DARK_OFFSETS));
}

void apply_calibration_blob(const CalibrationBlob &blob) {
  memcpy(UP_CAL_INPUTS, blob.up_inputs, sizeof(UP_CAL_INPUTS));
  memcpy(UP_CAL_FACTORS, blob.up_factors, sizeof(UP_CAL_FACTORS));
  memcpy(DOWN_CAL_INPUTS, blob.down_inputs, sizeof(DOWN_CAL_INPUTS));
  memcpy(DOWN_CAL_FACTORS, blob.down_factors, sizeof(DOWN_CAL_FACTORS));
  memcpy(UP_DARK_OFFSETS, blob.up_dark_offsets, sizeof(UP_DARK_OFFSETS));
  memcpy(DOWN_DARK_OFFSETS, blob.down_dark_offsets, sizeof(DOWN_DARK_OFFSETS));
}

bool load_calibration_from_flash() {
  CalibrationBlob blob;
  if (!calibration_preferences.begin(CALIBRATION_NAMESPACE, true)) return false;
  size_t stored_size = calibration_preferences.getBytesLength(CALIBRATION_KEY);
  if (stored_size != sizeof(CalibrationBlob)) {
    calibration_preferences.end();
    return false;
  }
  size_t read_size = calibration_preferences.getBytes(CALIBRATION_KEY, &blob, sizeof(blob));
  calibration_preferences.end();
  if (read_size != sizeof(blob)) return false;
  if (blob.magic != CALIBRATION_MAGIC || blob.version != CALIBRATION_VERSION) return false;
  apply_calibration_blob(blob);
  calibration_loaded_from_flash = true;
  return true;
}

bool save_calibration_to_flash() {
  CalibrationBlob blob;
  fill_calibration_blob(blob);
  if (!calibration_preferences.begin(CALIBRATION_NAMESPACE, false)) return false;
  size_t written = calibration_preferences.putBytes(CALIBRATION_KEY, &blob, sizeof(blob));
  calibration_preferences.end();
  if (written != sizeof(blob)) return false;
  calibration_loaded_from_flash = true;
  return true;
}

const char *calibration_source_name() {
  return calibration_loaded_from_flash ? "flash" : "header";
}

void read_sensor_channels(AS7265X &sensor, uint16_t values[AS7265X_CHANNEL_COUNT]) {
  values[0] = sensor.getA();
  values[1] = sensor.getB();
  values[2] = sensor.getC();
  values[3] = sensor.getD();
  values[4] = sensor.getE();
  values[5] = sensor.getF();
  values[6] = sensor.getG();
  values[7] = sensor.getH();
  values[8] = sensor.getR();
  values[9] = sensor.getI();
  values[10] = sensor.getS();
  values[11] = sensor.getJ();
  values[12] = sensor.getT();
  values[13] = sensor.getU();
  values[14] = sensor.getV();
  values[15] = sensor.getW();
  values[16] = sensor.getK();
  values[17] = sensor.getL();
}

float interpolate_calibration_factor(const float inputs[AS7265X_CAL_POINT_COUNT], const float factors[AS7265X_CAL_POINT_COUNT], float value) {
  if (value <= inputs[0]) return factors[0];

  const size_t last = AS7265X_CAL_POINT_COUNT - 1;
  if (value >= inputs[last]) {
    float x1 = inputs[last - 1];
    float x2 = inputs[last];
    float y1 = factors[last - 1];
    float y2 = factors[last];
    if (fabsf(x2 - x1) < 1e-6f) return y2;
    return y1 + ((value - x1) / (x2 - x1)) * (y2 - y1);
  }

  for (size_t idx = 1; idx < AS7265X_CAL_POINT_COUNT; ++idx) {
    if (value <= inputs[idx]) {
      float x1 = inputs[idx - 1];
      float x2 = inputs[idx];
      float y1 = factors[idx - 1];
      float y2 = factors[idx];
      if (fabsf(x2 - x1) < 1e-6f) return y2;
      return y1 + ((value - x1) / (x2 - x1)) * (y2 - y1);
    }
  }

  return factors[last];
}

float apply_channel_calibration(const SensorCalibrationView &view, size_t channel_index, float raw_value) {
  float input_value = raw_value - view.dark_offsets[channel_index];
  if (input_value < 0.0f) input_value = 0.0f;
  float factor = interpolate_calibration_factor(view.inputs[channel_index], view.factors[channel_index], input_value);
  return input_value * factor;
}

void print_status_block() {
  Serial.println("BEGIN_STATUS");
  Serial.print("fw=");
  Serial.println(CALIBRATION_FW_ID);
  Serial.print("calibration_source=");
  Serial.println(calibration_source_name());
  Serial.print("up_sensor=");
  Serial.println(up_ok ? "ready" : "missing");
  Serial.print("down_sensor=");
  Serial.println(down_ok ? "ready" : "missing");
  Serial.println("END_STATUS");
}

void print_calibration_status() {
  Serial.print("Calibration source: ");
  Serial.println(calibration_source_name());
}

void print_caldump(const SensorCalibrationView &view) {
  Serial.print("BEGIN_CALDUMP,");
  Serial.println(view.name);
  for (size_t channel = 0; channel < AS7265X_CHANNEL_COUNT; ++channel) {
    Serial.print(CHANNEL_LABELS[channel]);
    for (size_t point = 0; point < AS7265X_CAL_POINT_COUNT; ++point) {
      Serial.print(",");
      Serial.print(view.inputs[channel][point], 6);
    }
    for (size_t point = 0; point < AS7265X_CAL_POINT_COUNT; ++point) {
      Serial.print(",");
      Serial.print(view.factors[channel][point], 6);
    }
    Serial.println();
  }
  Serial.print("END_CALDUMP,");
  Serial.println(view.name);
}

void print_caldarkdump(const SensorCalibrationView &view) {
  Serial.print("BEGIN_CALDARK,");
  Serial.println(view.name);
  for (size_t channel = 0; channel < AS7265X_CHANNEL_COUNT; ++channel) {
    Serial.print(CHANNEL_LABELS[channel]);
    Serial.print(",");
    Serial.print(CHANNEL_WAVELENGTHS[channel]);
    Serial.print(",");
    Serial.println(view.dark_offsets[channel], 6);
  }
  Serial.print("END_CALDARK,");
  Serial.println(view.name);
}

void print_raw_channels_legacy(const char *label, const uint16_t values[AS7265X_CHANNEL_COUNT]) {
  Serial.println(label);
  for (size_t channel = 0; channel < AS7265X_CHANNEL_COUNT; ++channel) {
    Serial.print(CHANNEL_LABELS[channel]);
    Serial.print(" (");
    Serial.print(CHANNEL_WAVELENGTHS[channel]);
    Serial.print(" nm): ");
    Serial.println(values[channel]);
  }
}

bool parse_float_token(const char *token, float &value) {
  char *end = nullptr;
  value = strtof(token, &end);
  return end != token && end != nullptr && *end == '\0';
}

bool parse_int_token(const char *token, int &value) {
  char *end = nullptr;
  long parsed = strtol(token, &end, 10);
  if (end == token || end == nullptr || *end != '\0') return false;
  value = (int)parsed;
  return true;
}

void handle_calwrite_command(char *tokens[], size_t token_count) {
  if (token_count != (3 + (2 * AS7265X_CAL_POINT_COUNT))) {
    Serial.println("ERR calwrite usage");
    return;
  }

  SensorCalibrationView view;
  if (!get_sensor_calibration_view(tokens[1], view)) {
    Serial.println("ERR calwrite sensor");
    return;
  }

  int channel_index = -1;
  if (!parse_int_token(tokens[2], channel_index) || channel_index < 0 || channel_index >= (int)AS7265X_CHANNEL_COUNT) {
    Serial.println("ERR calwrite channel");
    return;
  }

  for (size_t point = 0; point < AS7265X_CAL_POINT_COUNT; ++point) {
    float parsed = 0.0f;
    if (!parse_float_token(tokens[3 + point], parsed)) {
      Serial.println("ERR calwrite input");
      return;
    }
    view.inputs[channel_index][point] = parsed;
  }

  for (size_t point = 0; point < AS7265X_CAL_POINT_COUNT; ++point) {
    float parsed = 0.0f;
    if (!parse_float_token(tokens[3 + AS7265X_CAL_POINT_COUNT + point], parsed)) {
      Serial.println("ERR calwrite factor");
      return;
    }
    view.factors[channel_index][point] = parsed;
  }

  Serial.print("OK calwrite ");
  Serial.print(view.name);
  Serial.print(" ");
  Serial.println(channel_index);
}

void handle_darkwrite_command(char *tokens[], size_t token_count) {
  if (token_count != 20) {
    Serial.println("ERR darkwrite usage");
    return;
  }

  SensorCalibrationView view;
  if (!get_sensor_calibration_view(tokens[1], view)) {
    Serial.println("ERR darkwrite sensor");
    return;
  }

  for (size_t channel = 0; channel < AS7265X_CHANNEL_COUNT; ++channel) {
    float parsed = 0.0f;
    if (!parse_float_token(tokens[2 + channel], parsed)) {
      Serial.println("ERR darkwrite value");
      return;
    }
    view.dark_offsets[channel] = parsed;
  }

  Serial.print("OK darkwrite ");
  Serial.println(view.name);
}

bool process_serial_command(const String &raw_command) {
  String command = raw_command;
  command.trim();
  if (command.length() == 0) return false;
  if (command.equalsIgnoreCase("m")) return true;

  char buffer[512];
  if (command.length() >= sizeof(buffer)) {
    Serial.println("ERR command too long");
    return false;
  }
  command.toCharArray(buffer, sizeof(buffer));

  char *tokens[SERIAL_COMMAND_MAX_TOKENS] = {nullptr};
  size_t token_count = 0;
  char *saveptr = nullptr;
  char *token = strtok_r(buffer, " ", &saveptr);
  while (token != nullptr && token_count < SERIAL_COMMAND_MAX_TOKENS) {
    tokens[token_count++] = token;
    token = strtok_r(nullptr, " ", &saveptr);
  }
  if (token_count == 0) return false;

  if (strcmp(tokens[0], "status") == 0) {
    print_status_block();
    return false;
  }
  if (strcmp(tokens[0], "calstatus") == 0) {
    print_calibration_status();
    return false;
  }
  if (strcmp(tokens[0], "calsave") == 0) {
    if (save_calibration_to_flash()) {
      Serial.println("OK calsave");
    } else {
      Serial.println("ERR calsave");
    }
    return false;
  }
  if (strcmp(tokens[0], "calwrite") == 0) {
    handle_calwrite_command(tokens, token_count);
    return false;
  }
  if (strcmp(tokens[0], "darkwrite") == 0) {
    handle_darkwrite_command(tokens, token_count);
    return false;
  }
  if (strcmp(tokens[0], "caldump") == 0 && token_count == 2) {
    SensorCalibrationView view;
    if (!get_sensor_calibration_view(tokens[1], view)) {
      Serial.println("ERR caldump sensor");
      return false;
    }
    print_caldump(view);
    return false;
  }
  if (strcmp(tokens[0], "caldarkdump") == 0 && token_count == 2) {
    SensorCalibrationView view;
    if (!get_sensor_calibration_view(tokens[1], view)) {
      Serial.println("ERR caldarkdump sensor");
      return false;
    }
    print_caldarkdump(view);
    return false;
  }

  Serial.print("ERR unknown ");
  Serial.println(command);
  return false;
}

bool poll_serial_commands() {
  static String serial_buffer;
  bool triggered = false;

  while (Serial.available()) {
    char c = (char)Serial.read();
    if (c == '\r') continue;
    if (c == '\n') {
      triggered = process_serial_command(serial_buffer) || triggered;
      serial_buffer = "";
      continue;
    }
    serial_buffer += c;
  }

  return triggered;
}

// ---------------- Sensor configuration ----------------
void configure_sensor_common(AS7265X &s) {
  s.disableIndicator();
  s.disableBulb(AS7265x_LED_WHITE);
  s.disableBulb(AS7265x_LED_IR);
  s.disableBulb(AS7265x_LED_UV);
  s.setIntegrationCycles(100);  // ~280 ms integration
  s.setGain(AS7265X_GAIN_37X);
}

bool try_init_up_sensor() {
  if (up_ok) return true;
  if (!sensor_UP.begin(Wire1)) return false;
  configure_sensor_common(sensor_UP);
  return true;
}

bool try_init_down_sensor() {
  if (down_ok) return true;
  if (!sensor_DOWN.begin(Wire)) return false;
  configure_sensor_common(sensor_DOWN);
  return true;
}

void i2c_init_buses_once() {
  Wire.begin(I2C1_SDA_PIN, I2C1_SCL_PIN, 400000);
  delay(10);
  Wire1.begin(I2C2_SDA_PIN, I2C2_SCL_PIN, 400000);
  delay(10);
}
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
void loop() {
  serviceBLE();
  retry_sensor_init_periodic();

  unsigned long now = millis();
  if (now - last_batt_sample_ms >= BATT_SAMPLE_PERIOD_MS) {
    last_batt_sample_ms = now;
    battery_soc = read_voltage_percent();
  }

  bool btn_now       = (digitalRead(BTN_MEASURE) == LOW);
  bool button_trigger = (!lastMeasureState && btn_now);
  bool serial_trigger = poll_serial_commands();
  lastMeasureState    = btn_now;

  if (button_trigger || serial_trigger) {
    if (serial_trigger) Serial.println(">> Serial trigger received.");

    up_ok   = false;
    down_ok = false;
    up_ok   = try_init_up_sensor();
    down_ok = try_init_down_sensor();
    updateBLEStatusValue();

    if (take_measurements_and_compute_ndvi()) {
      drawNDVIScreen();
    } else {
      drawStatusScreen();
    }
  }

  delay(20);
}

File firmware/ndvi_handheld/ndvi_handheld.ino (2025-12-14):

/*************************************************** 
  AS7265X dual-sensor outdoor NDVI meter
  - Bulbs OFF (ambient light)
  - Uses channels I (red-ish) and V (NIR-ish) for NDVI
  - UP sensor: incident light (sky)
  - DOWN sensor: reflected light (turf)
  - Prints all channels A–L, R–W
  - Shows NDVI + battery % on ST7789 240x240 LCD
  - Simple interface: large NDVI value or "LOW LIGHT"
  - Measure ONLY when A0 is pressed
****************************************************/

#include "SparkFun_AS7265X.h"
#include <Wire.h>
#include <WiFi.h>
#include <Adafruit_GFX.h>
#include <Adafruit_ST7789.h>
#include <SPI.h>

// ---------------- I2C ----------------
#define I2C1_SDA_PIN D7   // DOWN sensor
#define I2C1_SCL_PIN A4
#define I2C2_SDA_PIN SDA  // UP sensor
#define I2C2_SCL_PIN SCL

AS7265X sensor_DOWN;
AS7265X sensor_UP;

// ---------------- ST7789 240x240 LCD ----------------
#define SCREEN_WIDTH  240
#define SCREEN_HEIGHT 240
#define TFT_CS   D6  // Chip select
#define TFT_RST  D3  // Reset pin
#define TFT_DC   D2  // Data/Command pin

#define BLACK   0x0000
#define GREEN   0x07E0
#define RED     0xF800
#define YELLOW  0xFFE0  
#define WHITE   0xFFFF
#define BLUE    0x001F

Adafruit_ST7789 tft = Adafruit_ST7789(TFT_CS, TFT_DC, TFT_RST);

// ---------------- Button ----------------
#define BTN_MEASURE A0
bool lastMeasureState = false;

// ---------------- Battery (single LiPo 3.7V) ----------------
#define BATT A3

float soc_avg = 0.0;
int battery_soc = 0;

void configure_batt() {
  pinMode(BATT, INPUT);
  analogSetAttenuation(ADC_11db); // ESP32 ADC range up to ~3.6V at pin
}

// Piecewise LiPo voltage -> SoC (%) table (approx, under light load)
float voltagePoints[] = {
  3.30, // 0%
  3.45, // 10%
  3.55, // 20%
  3.68, // 30%
  3.73, // 40%
  3.79, // 50%
  3.85, // 60%
  3.92, // 70%
  4.00, // 80%
  4.08, // 90%
  4.12, // 95%
  4.20  // 100%
};

float socPoints[] = {
   0,
  10,
  20,
  30,
  40,
  50,
  60,
  70,
  80,
  90,
  95,
 100
};

// Map battery voltage to approximate SoC using linear interpolation
float voltageToPercent(float v) {
  // Clamp to min/max in table
  if (v <= voltagePoints[0]) return 0.0f;
  if (v >= voltagePoints[11]) return 100.0f;

  // Find segment
  for (int i = 0; i < 11; i++) {
    float v1 = voltagePoints[i];
    float v2 = voltagePoints[i + 1];
    if (v >= v1 && v <= v2) {
      float s1 = socPoints[i];
      float s2 = socPoints[i + 1];
      float t = (v - v1) / (v2 - v1);
      return s1 + t * (s2 - s1);
    }
  }
  return 0.0f; // shouldn't reach here
}

int read_voltage() {
  float raw = analogRead(BATT);
  // Same divider + fudge as your original code
  float voltage = (raw / 4095.0f) * 3.3f * 1.065f * 2.0f; // estimated battery voltage
  Serial.println("Voltage");
  Serial.println(raw);
  Serial.println(voltage);

  // Smooth the voltage
  if (soc_avg == 0.0f) {
    soc_avg = voltage;
  } else {
    soc_avg = 0.8f * soc_avg + 0.2f * voltage;
  }

  float pct = voltageToPercent(soc_avg);

  Serial.print("Battery raw V: ");
  Serial.print(voltage, 3);
  Serial.print(" V  | avg: ");
  Serial.print(soc_avg, 3);
  Serial.print(" V  | SoC: ");
  Serial.print(pct, 1);
  Serial.println(" %");

  // Clamp and convert to int
  if (pct < 0.0f) pct = 0.0f;
  if (pct > 100.0f) pct = 100.0f;
  return (int)pct;
}

// ---------------- NDVI ----------------
String message_NDVI = "---";
float ndvi = 0.0;

// ================= TRIAD SETUP =================
void setup_triad() {
  Serial.println("AS7265x Spectral Triad - outdoor mode (ambient, I/V NDVI)");

  // I2C for DOWN sensor
  Wire.begin(I2C1_SDA_PIN, I2C1_SCL_PIN, 100000);
  delay(10);

  // I2C for UP sensor
  Wire1.begin(I2C2_SDA_PIN, I2C2_SCL_PIN, 100000);
  delay(10);

  // Init sensors
  if (!sensor_DOWN.begin(Wire)) {
    Serial.println("Error: DOWN sensor not found!");
    while (1) delay(100);
  }
  if (!sensor_UP.begin(Wire1)) {
    Serial.println("Error: UP sensor not found!");
    while (1) delay(100);
  }

  // Turn off status LEDs
  sensor_UP.disableIndicator();
  sensor_DOWN.disableIndicator();

  // Ensure bulbs are OFF for outdoor NDVI
  sensor_UP.disableBulb(AS7265x_LED_WHITE);
  sensor_DOWN.disableBulb(AS7265x_LED_WHITE);

  // Integration time & gain (tune if needed)
  // setIntegrationCycles(N) -> N * 2.8 ms
  sensor_UP.setIntegrationCycles(50);    // ~140 ms
  sensor_DOWN.setIntegrationCycles(50);

  // Gains: AS7265X_GAIN_1X, _37X, _16X, _64X
  sensor_UP.setGain(AS7265X_GAIN_37X);
  sensor_DOWN.setGain(AS7265X_GAIN_37X);

  Serial.println("Triad setup complete.");
}

// ================= MEASURE & NDVI (I/V) =================
void getTriadReadings() {
  // ---- Ambient measurement UP (incident) ----
  sensor_UP.takeMeasurements();
  float aU = sensor_UP.getCalibratedA();
  float bU = sensor_UP.getCalibratedB();
  float cU = sensor_UP.getCalibratedC();
  float dU = sensor_UP.getCalibratedD();
  float eU = sensor_UP.getCalibratedE();
  float fU = sensor_UP.getCalibratedF();
  float gU = sensor_UP.getCalibratedG();
  float hU = sensor_UP.getCalibratedH();
  float iU = sensor_UP.getCalibratedI(); // RED (chosen)
  float jU = sensor_UP.getCalibratedJ();
  float kU = sensor_UP.getCalibratedK();
  float lU = sensor_UP.getCalibratedL();
  float rU = sensor_UP.getCalibratedR();
  float sU = sensor_UP.getCalibratedS();
  float tU = sensor_UP.getCalibratedT();
  float uU = sensor_UP.getCalibratedU();
  float vU = sensor_UP.getCalibratedV(); // NIR (chosen)
  float wU = sensor_UP.getCalibratedW();

  // ---- Ambient measurement DOWN (reflected) ----
  sensor_DOWN.takeMeasurements();
  float aD = sensor_DOWN.getCalibratedA();
  float bD = sensor_DOWN.getCalibratedB();
  float cD = sensor_DOWN.getCalibratedC();
  float dD = sensor_DOWN.getCalibratedD();
  float eD = sensor_DOWN.getCalibratedE();
  float fD = sensor_DOWN.getCalibratedF();
  float gD = sensor_DOWN.getCalibratedG();
  float hD = sensor_DOWN.getCalibratedH();
  float iD = sensor_DOWN.getCalibratedI(); // RED (down)
  float jD = sensor_DOWN.getCalibratedJ();
  float kD = sensor_DOWN.getCalibratedK();
  float lD = sensor_DOWN.getCalibratedL();
  float rD = sensor_DOWN.getCalibratedR();
  float sD = sensor_DOWN.getCalibratedS();
  float tD = sensor_DOWN.getCalibratedT();
  float uD = sensor_DOWN.getCalibratedU();
  float vD = sensor_DOWN.getCalibratedV(); // NIR (down)
  float wD = sensor_DOWN.getCalibratedW();

  // ---- NDVI using I (red) and V (NIR) ----
  float red_UP = iU;
  float nir_UP = vU;
  float red_DN = iD;
  float nir_DN = vD;

  float red_ratio = (red_UP != 0.0f) ? (red_DN / red_UP) : 0.0f;
  float nir_ratio = (nir_UP != 0.0f) ? (nir_DN / nir_UP) : 0.0f;

  float denom = nir_ratio + red_ratio;
  if (denom != 0.0f) {
    ndvi = (nir_ratio - red_ratio) / denom;
  } else {
    ndvi = 0.0f;
  }
  message_NDVI = String(ndvi, 3);

  // Update battery reading each time we measure
  battery_soc = read_voltage();
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

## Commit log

2026-10-14 Add portal Wi-Fi rescan button
2026-10-14 Trust GitHub's current certificate chain for OTA
2026-10-23 Reduce OTA TLS memory and simplify calibration runtime
